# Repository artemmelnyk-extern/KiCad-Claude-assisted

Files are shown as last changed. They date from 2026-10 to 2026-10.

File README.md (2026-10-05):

# Safety inputs for Arduino UNO: 2 e-stops + 2 lidars through PC817

An Arduino UNO shield with **four isolated 24 V inputs**: two emergency-stop buttons (one
normally-closed contact each) and two safety-lidar outputs. Each input goes through a PC817
optocoupler, so the 24 V side is electrically isolated from the microcontroller. It works unchanged on
the **UNO R4 WiFi** (5 V logic) and the **UNO Q** (3.3 V logic).

The KiCad schematic and board in this repository are **generated by Python scripts**. The scripts are
the source; the KiCad files are their output.

Schematic

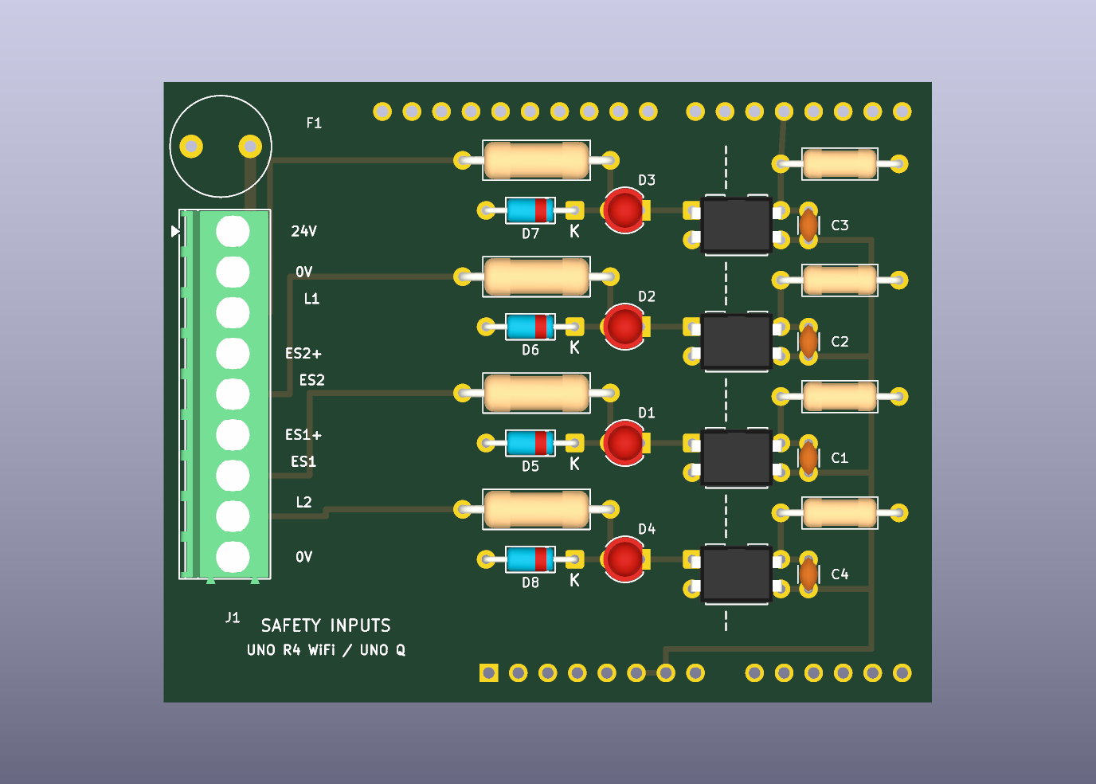
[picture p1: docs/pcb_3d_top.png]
Board, 3D view


## The circuit

All four channels are the same; only the terminal wiring and the resistor value differ.

```
 e-stop:  24V ─[F1 T2A]─► ESn+ ──(button, NC)── ESn ─┐
 lidar:   lidar output (24 V when the zone is clear) ─ Ln ─┤
                                                      │
        ───[R]───┬─[LED]─► PC817 pin 1      pin 4 ─┬──────┬─ D2..D5
                 │                                  │      │
             [1N4148]                            [10k]   [C 100n, optional]
                 │                                  │      │
 0V ─────────────┴───────── PC817 pin 2           IOREF    │
                                             pin 3 ────────┴─ GND
```

| Pin | Input | Terminals | Series resistor (½ W) | Current |
|---|---|---|---|---|
| D2 | e-stop 1 | `ES1+`, `ES1` | R1 = 3.3 kΩ | 6.3 mA |
| D3 | e-stop 2 | `ES2+`, `ES2` | R2 = 3.3 kΩ | 6.3 mA |
| D4 | lidar 1 | `L1`, `0V` | R3 = 4.7 kΩ | 4.4 mA |
| D5 | lidar 2 | `L2`, `0V` | R4 = 4.7 kΩ | 4.4 mA |

| State | LED | Pin |
|---|---|---|
| Current flows: button released, or lidar zone clear | lit | **LOW = OK** |
| No current: button pressed, zone occupied, wire cut, connector unplugged, 24 V lost, fuse blown | off | **HIGH = stop** |

Every wiring failure reads as "stop".

- **The 24 V comes from an external source.** The board has none of its own: connect the source's
  plus to the `24V` screw and its minus to a `0V` screw. The board draws about 13 mA from it (the two
  e-stop loops). The lidars must share this same 0 V. The schematic draws the source in the
  "EXTERNAL" box.
- **The e-stop buttons are external.** The schematic draws them left of the terminal block, in a
  dashed box marked "EXTERNAL - not on the board": S1 between `ES1+` and `ES1`, S2 between `ES2+` and
  `ES2`, each with one normally-closed contact (two terminals). They are drawings only, so they
  appear in neither the netlist nor the board. Which button is front and which is rear is a choice
  made at installation; the sheet labels S1 front and S2 rear.
- **Terminal block J1**, top to bottom: `24V`, `0V`, `L1`, `ES2+`, `ES2`, `ES1+`, `ES1`, `L2`, `0V`.
  The order follows the channels on the board.
- **F1 (T2A)** protects the 24 V wires that leave the board for the buttons.
- **E-stop loops carry 6.3 mA** because switch contacts need a minimum current to stay reliable (often
  about 5 mA at 24 V; check the button's data sheet). A lidar output is electronic and needs none.
- **R1–R4 must be real ½ W parts** (body about 9 × 3.2 mm). At 28.8 V a 3.3 kΩ dissipates 0.20 W
  (40 % of ½ W) and a 4.7 kΩ 0.14 W (28 %). A ¼ W-size resistor (6 × 2.3 mm) sold as ½ W would run
  at 80 % of its real rating: measure the body before fitting. The 10 kΩ pull-ups R5–R8 dissipate
  2.5 mW; any rating will do.
- **C1–C4 (100 nF) are optional.** With the 10 kΩ pull-up they form a 1 ms filter on the rising
  (stop) edge: an opening shorter than about 1.5 ms never reaches the Arduino's HIGH threshold, and
  every real stop is seen about 1.6 ms later. Fitted, they remove contact bounce and a lidar's
  output test pulses in hardware; they also hide those short openings from the firmware, which can
  then no longer count them. Leave them out to observe the raw signal. The timing figures are
  calculated, not measured.
- The 1N4148 protects the LEDs against a reversed connection (the PC817 LED tolerates only 6 V).
- `0V` (24 V side) and `GND` (Arduino) are separate nets. Do not join them: that is the isolation.
  The lidars' 0 V must be connected to this board's `0V`.
- Each input is **single-channel**. A short across a button's two wires, or a shorted optocoupler
  output, reads as "OK" and is not detected. This is not a certified safety function.

## One board, two Arduinos

The pull-ups are tied to the header's **IOREF** pin, not to 5V. IOREF carries the logic voltage of
whichever board is plugged in, so the outputs swing to 5 V on a UNO R4 WiFi and to 3.3 V on a UNO Q,
with no jumper and no part change. The 24 V side is identical for both.

| | UNO R4 WiFi | UNO Q |
|---|---|---|
| Logic voltage (IOREF) | 5 V | 3.3 V |
| Pull-up current through 10 kΩ | 0.5 mA | 0.33 mA |
| Output LOW (PC817 saturated) | ≤ 0.2 V | ≤ 0.2 V |

Only pins that exist on every UNO-format board are used. The UNO Q figures come from its published
specification and have not been tried on hardware here: check the IOREF voltage with a multimeter
before plugging the bench onto a UNO Q.

## Repository layout

| Path | Content |
|---|---|
| `generate.py` | writes the schematic, project and symbol library in `kicad/`. Standard-library Python 3 |
| `generate_pcb.py` | writes the board `kicad/pc817_bench.kicad_pcb`: placement and routing. Needs KiCad's Python (`pcbnew`) |
| `kicad/` | generated KiCad project: open `pc817_bench.kicad_pro` |
| `docs/` | schematic (PDF, SVG), board layers (SVG), 3D view (PNG) |
| `firmware/pc817_two_inputs/` | Arduino sketch that prints every edge with its timing |
| `check.sh` | regenerate everything, run KiCad's schematic and board rule checks, export `docs/` |

## Use

```bash
./check.sh     # needs kicad-cli and KiCad's Python, KiCad 9 or later
```

With the Flatpak build of KiCad:

```bash
KICAD_CLI="flatpak run --command=kicad-cli --filesystem=$PWD org.kicad.KiCad" \
KICAD_PYTHON="flatpak run --command=python3 --filesystem=$PWD org.kicad.KiCad" ./check.sh
```

To change the circuit or the layout, edit the scripts and run `check.sh` again. Edits made in the
KiCad editors are overwritten by the next run.

## The board

A two-layer, through-hole Arduino UNO shield, 66 × 53 mm, four channels at a 10 mm pitch.

- 24 V parts on the left, logic on the right. The gap under the optocouplers is the isolation
  barrier. One logic track (D5) runs in that gap on the solder side, 4.3 mm from the 24 V pins.
- Rows, top to bottom: lidar 1, e-stop 2, e-stop 1, lidar 2. This order lets each output reach its
  header pin without crossing another.
- The 9-way screw terminal (3.5 mm pitch) runs down the left edge with the fuse above it. On a
  UNO R4 WiFi this is above the USB-C connector, and the lowest terminals reach the power jack.
- Signal tracks are 0.5 mm, the fused 24 V tracks 1 mm. The 24 V return runs on the solder side.
- Part references of the resistors, diodes and optocouplers are printed under the parts.
- The optional capacitors stand right of the optocouplers, across pins 4 and 3.
- The library footprint `Module:Arduino_UNO_R3` is placed **flipped to the back side**, because a
  shield sits above the Arduino. Unflipped, the shield comes out mirrored. Its courtyard is removed,
  since the shield's parts are meant to be inside the Arduino's outline.
- Of the three GND header pins, the two on the power header are used.

## How the generators work

`generate_pcb.py` uses KiCad's `pcbnew` Python module: it loads the library footprints named in the
schematic, assigns nets from the exported netlist, places each part at fixed coordinates and adds
the tracks segment by segment. There is no autorouter.

`generate.py` uses no KiCad API. It writes KiCad's text file format (S-expressions) directly:

- the symbols (resistor, LED, diode, fuse, PC817, terminal block, Arduino UNO header) are defined in the script and embedded in the
  schematic, and also written to `kicad/bench.kicad_sym`;
- `place()`, `wire()`, `label()` and `junction()` append one schematic item each;
- `channel(k, y)` draws one complete input channel, and is called twice.

## Limits

- The board passes KiCad's design-rule check with default rules (one expected warning: the Arduino
  footprint differs from its library copy). **It has not been manufactured or assembled.** Before
  ordering, check the header orientation against a real Arduino using a 1:1 print, and the height of
  the terminal block's solder pins above the Arduino's connectors.
- No mounting holes, no test points, no copper zones.
- The files are written in the KiCad 7 format. KiCad 8 and later open them and show a notice that the
  file will be converted when saved. Checked with KiCad 10.0.6: loads, 0 rule-check violations.
- The Arduino is drawn as one symbol with the standard UNO shield header. Only IOREF, GND, D2 and D3
  are used; the other pins carry no-connect marks. Its pin numbers are the pad numbers of the library footprint.
- A shorted optocoupler output transistor also reads as "released", undetected.

## Datasheet

PC817: 4-pin DIP, pin 1 anode, 2 cathode, 3 emitter, 4 collector; current transfer ratio 50–600 % at
5 mA; isolation 5000 Vrms. Datasheets are available from Sharp and from second-source manufacturers.

## Hand-built version

The branch `proto-shield` adds a build plan for the same circuit on a proto shield with isolated
pads: a hole-by-hole layout, solder bridges and wires, checked against this schematic's netlist.

## Licence

MIT, see [LICENSE](LICENSE). It covers the script, the sketch and the generated KiCad files.

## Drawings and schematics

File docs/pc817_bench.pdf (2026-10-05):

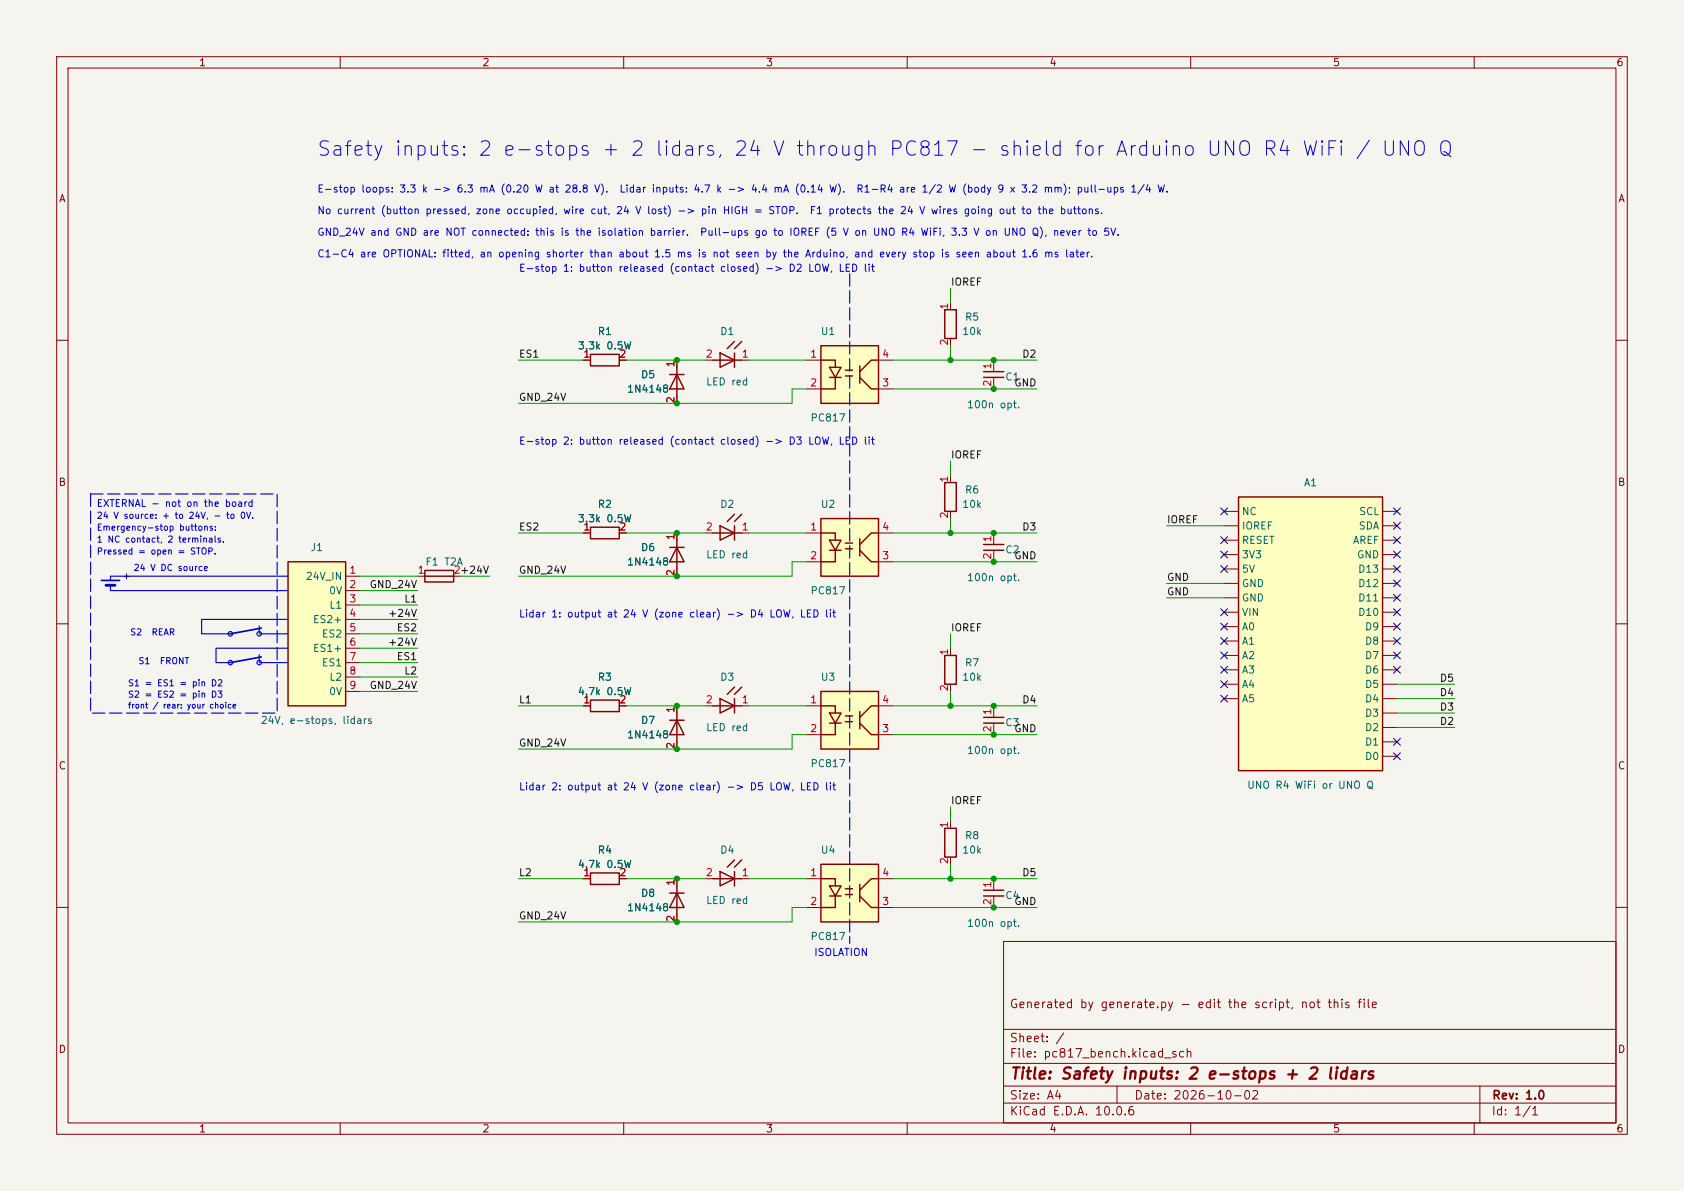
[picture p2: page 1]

E-stop 2: button released (contact closed) -> D3 LOW, LED lit E-stop 1: button released (contact closed) -> D2 LOW, LED lit
IOREF GND_24V ES1 GND_24V ES2

AREF SDA SCL A1 UNO R4 WiFi or UNO Q

front / rear: your choice Emergency-stop buttons: S2 = ES2 = pin D3
S1 = ES1 = pin D2 Pressed = open = STOP. 1 NC contact, 2 terminals. S2 REAR

24 V DC source
Lidar 1: output at 24 V (zone clear) -> D4 LOW, LED lit Lidar 2: output at 24 V (zone clear) -> D5 LOW, LED lit +

Generated by generate.py - edit the script, not this file

Sheet: /
File: pc817_bench.kicad_sch
Title: Safety inputs: 2 e-stops + 2 lidars

Size: A4 | Rev: 1.0
KiCad E.D.A. 10.0.6 | Id: 1/1

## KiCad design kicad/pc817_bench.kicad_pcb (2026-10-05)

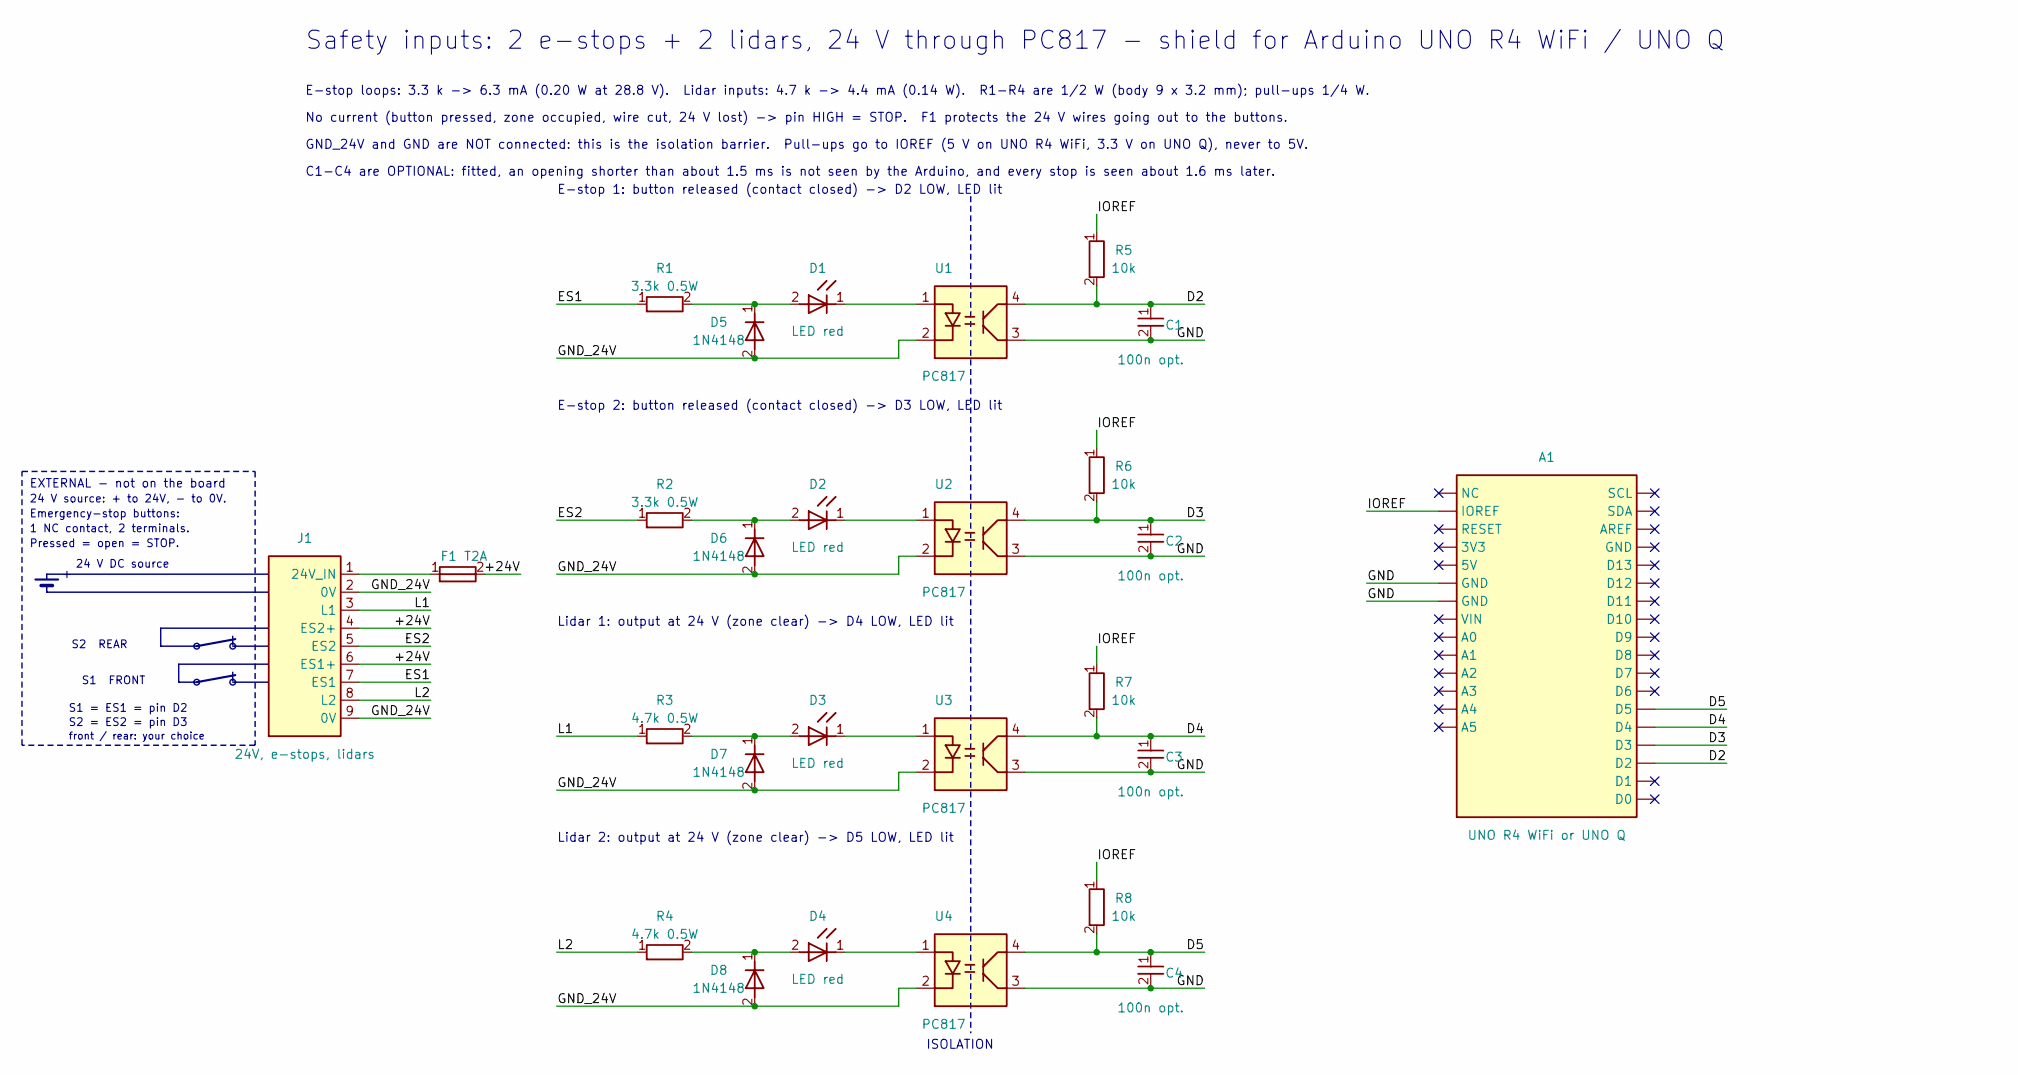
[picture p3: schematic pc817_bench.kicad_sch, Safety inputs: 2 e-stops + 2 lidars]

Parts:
A1: UNO R4 WiFi or UNO Q; Arduino_UNO_R3
C1, C2, C3, C4: 100n opt.; C_Disc_D3.0mm_W1.6mm_P2.50mm
D1, D2, D3, D4: LED red; LED_D3.0mm
D5, D6, D7, D8: 1N4148; D_DO-35_SOD27_P7.62mm_Horizontal
F1: T2A; Fuse_Littelfuse_372_D8.50mm
J1: 24V, e-stops, lidars; TerminalBlock_Phoenix_PT-1,5-9-3.5-H_1x09_P3.50mm_Horizontal
R1, R2: 3.3k 0.5W; R_Axial_DIN0309_L9.0mm_D3.2mm_P12.70mm_Horizontal
R3, R4: 4.7k 0.5W; R_Axial_DIN0309_L9.0mm_D3.2mm_P12.70mm_Horizontal
R5, R6, R7, R8: 10k; R_Axial_DIN0207_L6.3mm_D2.5mm_P10.16mm_Horizontal
U1, U2, U3, U4: PC817; DIP-4_W7.62mm

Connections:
/+24V: F1.2, J1.4 (ES2+), J1.6 (ES1+)
/D2: A1.17 (D2), C1.1, R5.2, U1.4 (C)
/D3: A1.18 (D3), C2.1, R6.2, U2.4 (C)
/D4: A1.19 (D4), C3.1, R7.2, U3.4 (C)
/D5: A1.20 (D5), C4.1, R8.2, U4.4 (C)
/ES1: J1.7 (ES1), R1.1
/ES2: J1.5 (ES2), R2.1
/GND: A1.6 (GND), A1.7 (GND), C1.2, C2.2, C3.2, C4.2, U1.3 (E), U2.3 (E), U3.3 (E), U4.3 (E)
/GND_24V: D5.2 (A), D6.2 (A), D7.2 (A), D8.2 (A), J1.2 (0V), J1.9 (0V), U1.2 (K), U2.2 (K), U3.2 (K), U4.2 (K)
/IOREF: A1.2 (IOREF), R5.1, R6.1, R7.1, R8.1
/L1: J1.3 (L1), R3.1
/L2: J1.8 (L2), R4.1
unnamed: D1.2 (A), D5.1 (K), R1.2
unnamed: D1.1 (K), U1.1 (A)
unnamed: D2.2 (A), D6.1 (K), R2.2
unnamed: D2.1 (K), U2.1 (A)
unnamed: D3.2 (A), D7.1 (K), R3.2
unnamed: D3.1 (K), U3.1 (A)
unnamed: D4.2 (A), D8.1 (K), R4.2
unnamed: D4.1 (K), U4.1 (A)
unnamed: F1.1, J1.1 (24V_IN)

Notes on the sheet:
E-stop 1: button released (contact closed) -> D2 LOW, LED lit
E-stop 2: button released (contact closed) -> D3 LOW, LED lit
Lidar 1: output at 24 V (zone clear) -> D4 LOW, LED lit
Lidar 2: output at 24 V (zone clear) -> D5 LOW, LED lit
24 V DC source
S1 FRONT
S2 REAR
EXTERNAL - not on the board
24 V source: + to 24V, - to 0V.
Emergency-stop buttons:
1 NC contact, 2 terminals.
Pressed = open = STOP.
S1 = ES1 = pin D2
S2 = ES2 = pin D3
front / rear: your choice
Safety inputs: 2 e-stops + 2 lidars, 24 V through PC817 - shield for Arduino UNO R4 WiFi / UNO Q
E-stop loops: 3.3 k -> 6.3 mA (0.20 W at 28.8 V). Lidar inputs: 4.7 k -> 4.4 mA (0.14 W). R1-R4 are 1/2 W (body 9 x 3.2 mm); pull-ups 1/4 W.
C1-C4 are OPTIONAL: fitted, an opening shorter than about 1.5 ms is not seen by the Arduino, and every stop is seen about 1.6 ms later.
No current (button pressed, zone occupied, wire cut, 24 V lost) -> pin HIGH = STOP. F1 protects the 24 V wires going out to the buttons.
GND_24V and GND are NOT connected: this is the isolation barrier. Pull-ups go to IOREF (5 V on UNO R4 WiFi, 3.3 V on UNO Q), never to 5V.
ISOLATION

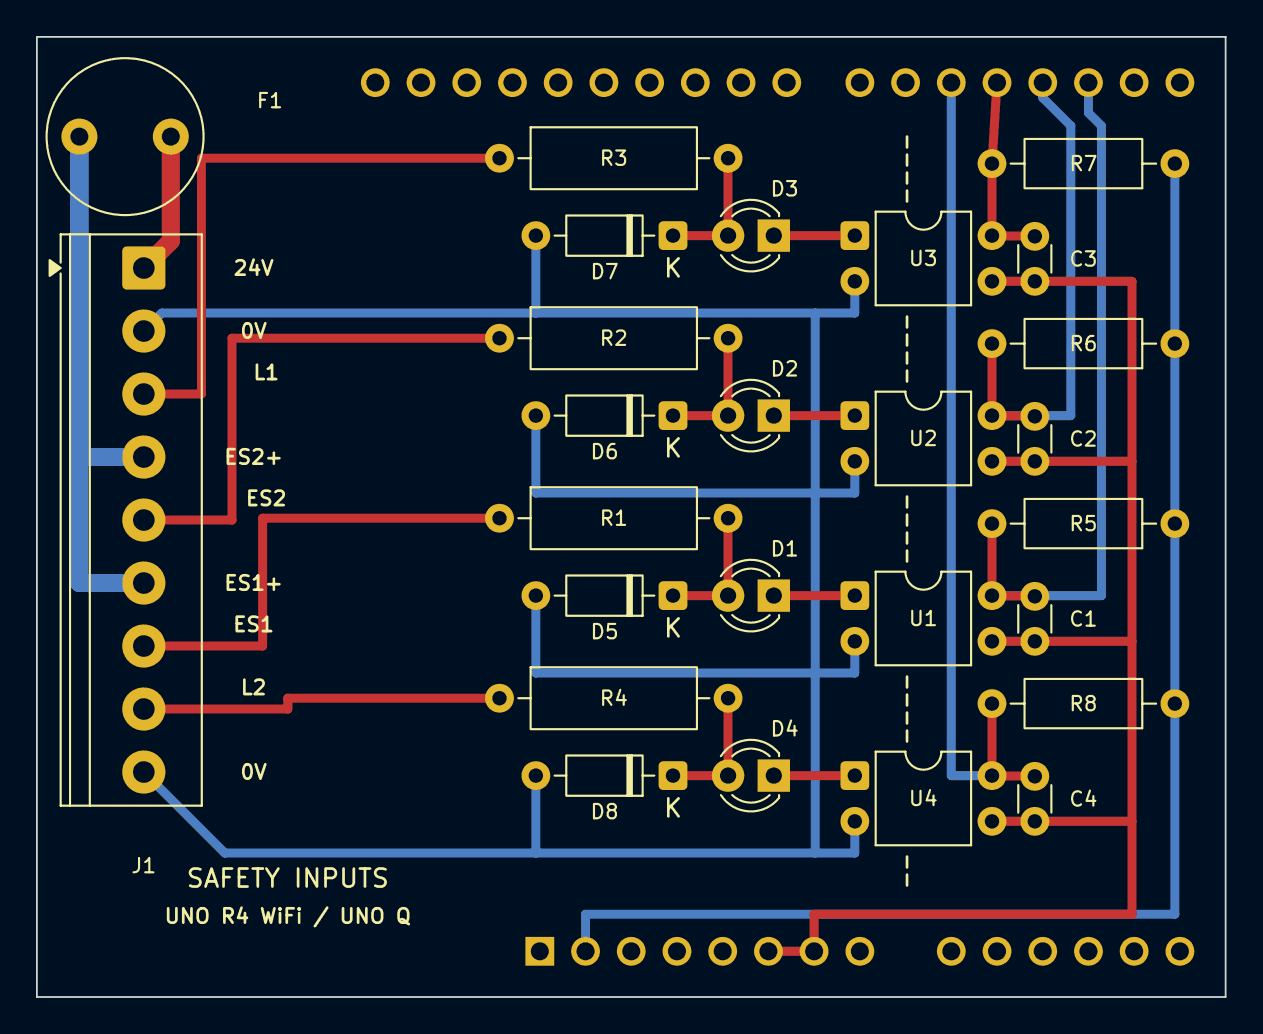
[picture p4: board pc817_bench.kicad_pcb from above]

Board: 2 copper layers, 66.0 x 53.3 mm, 27 parts (1 on the bottom side), 21 nets.

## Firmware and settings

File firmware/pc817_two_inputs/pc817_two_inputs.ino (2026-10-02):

/*
  pc817_two_inputs.ino  (now four inputs; the folder name is kept)
  Reads the four isolated 24 V inputs of the shield (Arduino UNO R4 WiFi or UNO Q; any
  UNO-format board) and prints every edge with its time and the duration of the state that
  just ended. No debounce: the point of the bench is to see bounce and short pulses.

    D2 = e-stop 1   D3 = e-stop 2   D4 = lidar 1   D5 = lidar 2

  Wiring: see docs/pc817_bench.pdf. The board has external 10 k pull-ups to IOREF, so the
  pins are plain INPUTs. Current flows (button released / zone clear) -> pin LOW = OK.
*/

const uint8_t N = 4;
const uint8_t PINS[N] = {2, 3, 4, 5};
const char *NAMES[N] = {"ES1", "ES2", "L1", "L2"};

bool lastOk[N];
unsigned long lastEdgeUs[N];

bool isOk(uint8_t i) { return digitalRead(PINS[i]) == LOW; }

void setup() {
  Serial.begin(115200);
  while (!Serial && millis() < 2000) {}
  unsigned long now = micros();
  for (uint8_t i = 0; i < N; i++) {
    pinMode(PINS[i], INPUT);
    lastOk[i] = isOk(i);
    lastEdgeUs[i] = now;
    Serial.print(NAMES[i]);
    Serial.println(lastOk[i] ? " OK (start)" : " STOP (start)");
  }
}

void loop() {
  for (uint8_t i = 0; i < N; i++) {
    bool ok = isOk(i);
    if (ok == lastOk[i]) continue;
    unsigned long now = micros();
    unsigned long heldUs = now - lastEdgeUs[i];   // wraps correctly after ~71 min
    lastEdgeUs[i] = now;
    lastOk[i] = ok;
    Serial.print(NAMES[i]);
    Serial.print(ok ? " OK   after " : " STOP after ");
    Serial.print(heldUs);
    Serial.println(" us");
  }
}

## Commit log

2026-10-02 PC817 24 V input bench: Python-generated KiCad schematic, test sketch
    Two isolated 24 V input channels for an Arduino UNO (D2, D3). generate.py
    writes the KiCad project in kicad/; check.sh runs KiCad's rule check and
    exports docs/. Checked with KiCad 10.0.6: 0 violations.
    [pc817_bench.kicad_sch]
2026-10-02 Draw the Arduino UNO R4 WiFi as a full header symbol instead of a 4-pin connector
    Unused pins carry no-connect marks; all three GND pins join the GND net.
    Rule check: 0 violations (KiCad 10.0.6).
    [pc817_bench.kicad_sch]
2026-10-02 Pull-ups to IOREF so the bench works on both UNO R4 WiFi (5 V) and UNO Q (3.3 V)
    The Arduino symbol is now the standard UNO shield header only.
    [pc817_bench.kicad_sch]
2026-10-02 Add the board: generated two-layer UNO shield layout
    generate_pcb.py places and routes the parts with KiCad's pcbnew module, from
    the netlist exported by the schematic. The Arduino footprint is flipped to
    the back side so the shield is not mirrored. check.sh now builds and checks
    both schematic and board (DRC: no errors, schematic parity OK, KiCad 10.0.6).
    Schematic: footprints assigned; the GND pin next to AREF is left unconnected.
    [pc817_bench.kicad_pcb, pc817_bench.kicad_sch]
2026-10-02 Two e-stop loops: fused 24 V out to each button, return through the PC817 channel
    J1 is now a 6-way terminal (24V, ES1+, ES1, ES2+, ES2, 0V) and F1 (T2A) protects
    the 24 V leaving the board. Series resistors 2 x 1.5k: 6.9 mA loop current.
    Board re-routed; DRC: no errors, schematic parity OK (KiCad 10.0.6).
    [pc817_bench.kicad_pcb, pc817_bench.kicad_sch]
2026-10-02 Four channels: two e-stop loops (D2, D3) and two lidar inputs (D4, D5)
    9-way 3.5 mm terminal, fuse on the 24 V going out to the buttons, channels at
    10 mm pitch. DRC: no errors, schematic parity OK (KiCad 10.0.6).
    [pc817_bench.kicad_pcb, pc817_bench.kicad_sch]
2026-10-03 Optional 100 nF filter capacitor on each output (C1-C4)
    Between the optocoupler output and logic GND: 1 ms with the 10 k pull-up.
    Board: capacitors right of the optocouplers; the two middle output tracks
    move right to clear them. DRC: no errors, schematic parity OK.
    [pc817_bench.kicad_pcb, pc817_bench.kicad_sch]
2026-10-05 One 1/2 W series resistor per channel instead of two 1/4 W
    E-stops: 3.3k (6.3 mA, 0.20 W at 28.8 V). Lidars: 4.7k (4.4 mA, 0.14 W).
    Pull-ups renumbered R5-R8. Board: DIN0309 footprint, 12.7 mm pitch.
    DRC: no errors, schematic parity OK.
    [pc817_bench.kicad_pcb, pc817_bench.kicad_sch]
2026-10-05 Schematic: draw the two external e-stop buttons and how they wire to the terminals
    S1 (front) between ES1+ and ES1, S2 (rear) between ES2+ and ES2, in a dashed
    box marked as external. Graphics only: no change to the netlist or the board.
    The sheet content is shifted right to make room.
    [pc817_bench.kicad_pcb, pc817_bench.kicad_sch]
2026-10-05 Schematic: external-buttons box sized for a shared ES+ screw too
    [pc817_bench.kicad_pcb]
2026-10-05 Schematic: draw the external 24 V source and where it connects (24V and 0V screws)
    [pc817_bench.kicad_pcb, pc817_bench.kicad_sch]
